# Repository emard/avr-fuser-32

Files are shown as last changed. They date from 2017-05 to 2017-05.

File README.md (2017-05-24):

# AVR-Fuser 32

3-in-1 Resurrector programmer for AVR chips

    HVPP: High-Voltage Parallel Programmer
    HVSP: High-Voltage Serial Programmer
    ISP:  In-System Programmer (SPI)

Based on [AVR-Doper](https://www.obdev.at/products/vusb/avrdoper.html)
firmware running on ATMEGA32 in DIP-40 socket.

AVRDUDE compatible, USB powered, onboard 5V->12V converter,
10-pin ISP header, 20-pin HVPP/HVSP header and 
adapter PCB for many popular DIP packages.

Quick mode without PC and avrdude: Pushbutton
erases chip to factory default state.

Complete with firmware, bootloader, kicad schematics and PCB 
for the programmer and sockets adapter.

Supported devices (I tried many but not all of them :)

    ATMEGA 8, 16, 32, 162, 168P, 328P, 16M1, 32M1, 64M1, 8515, 8535
    ATTINY 11, 13, 15, 26, 84, 85, 2313, 4313

# Remark

This is my old project, just uplodaded to github in order
not to get lost, without trying it to compile or open 
since a long time.

May need some fitting for new avr-gcc and kicad 4.x

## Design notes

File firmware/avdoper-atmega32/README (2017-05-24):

use bootloader

make fuser

press start + reset

make flash

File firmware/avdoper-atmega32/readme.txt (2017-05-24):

small capacitor GND-VCC is needed for attiny84 flash programming

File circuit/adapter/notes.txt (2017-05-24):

#!/bin/sh

# extract pdf page
pdftk HV_PROG_Adapter2.pdf cat 3 output board.pdf

# converted from pdf to ppm in 300 dpi resolution
pdftoppm -r 300 board.pdf  > board.gif

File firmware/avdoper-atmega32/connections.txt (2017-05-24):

programmer       ISP               ISP

ATMEGA8          ATMEGA162         ATTINY84
-------          ---------         --------
25 PC2     ->    SCK    8          SCK   9
26 PC3 inv <-    MISO   7          MISO  8
27 PC4     ->    MOSI   6          MOSI  7
28 PC5 inv ->    RESET  9          RESET 4
   +5V           VCC    40         VCC   1
   GND           GND    20         GND   14

ATMEGA8          ATTINY84
-------          --------
11 PD5           8
12 PD6           7
13 PD7           9
17 MOSI          2
   HVRESET       4
   GND           GND 14,13,12,10
   +5V           VCC 1

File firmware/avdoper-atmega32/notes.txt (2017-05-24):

here works HVPP and HVSP

[x] find only what the F***K enables JTAG
    on this MCU. The disabling in main is not sufficient
[x] fusereset doesn't work for hvsp,
    read signature gives 0xff, despite set or clr weak pull up SDO
[ ] sometimes there's protocolr error: (dmesg shows no usb error)
Writing |                                                    | 0% 0.00sError
sending message: error sending control message: Protocol error

[ ] consecutevely reading low/high fuse on atmega162, atmega8
    sometimes returns 0xff
    -> bringing up and down progmode causes this
    delays in leaveprogmode helped for m8
    still if there's delay after leving progmode, m8 gives errors

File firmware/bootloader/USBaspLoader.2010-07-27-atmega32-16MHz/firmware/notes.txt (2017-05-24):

useable if only read-while-write section (RWW)
0x0000-0x6fff

NRWW section 0x7000-0x77ff behaves different, 
halting cpu while writing (writing fails)
it should be possible to write there with modified code for NRWW section

it could not be possible to verify or read NRWW section

to enter bootloader,
hold "START" button, press "RESET"
release "RESET", release "START

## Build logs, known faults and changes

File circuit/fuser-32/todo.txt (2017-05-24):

[x] LED diode - padovi na donjoj strani
    nemaju solmask
[ ] za tipke rupe za pinove trebaju biti bliže
[ ] resistors 330 ohm to all 20pin lines

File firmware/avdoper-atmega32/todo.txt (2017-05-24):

HVPP mode:

[x] fuser reads 1st byte of signature, all the rest are 0xff
    target chip was not fully inserted into socket

byte eeprom access doesn't work
(writes just 0, reads wrong)

(rewrite count tracking)

avrdude -t 
write eeprom 0 1
-> instead of 1 it writes 0 to eeprom

dump eeprom 0 6
-> works correctly

write to eeprom in byte mode in ISP mode works correctly
write to eeprom in page mode in hvpp works correctly

works first time, then fails

[x] fix control message timeout in version 1.02
    disabled cdc support, enabled fast crc routine
    continuous verification now works w/o error

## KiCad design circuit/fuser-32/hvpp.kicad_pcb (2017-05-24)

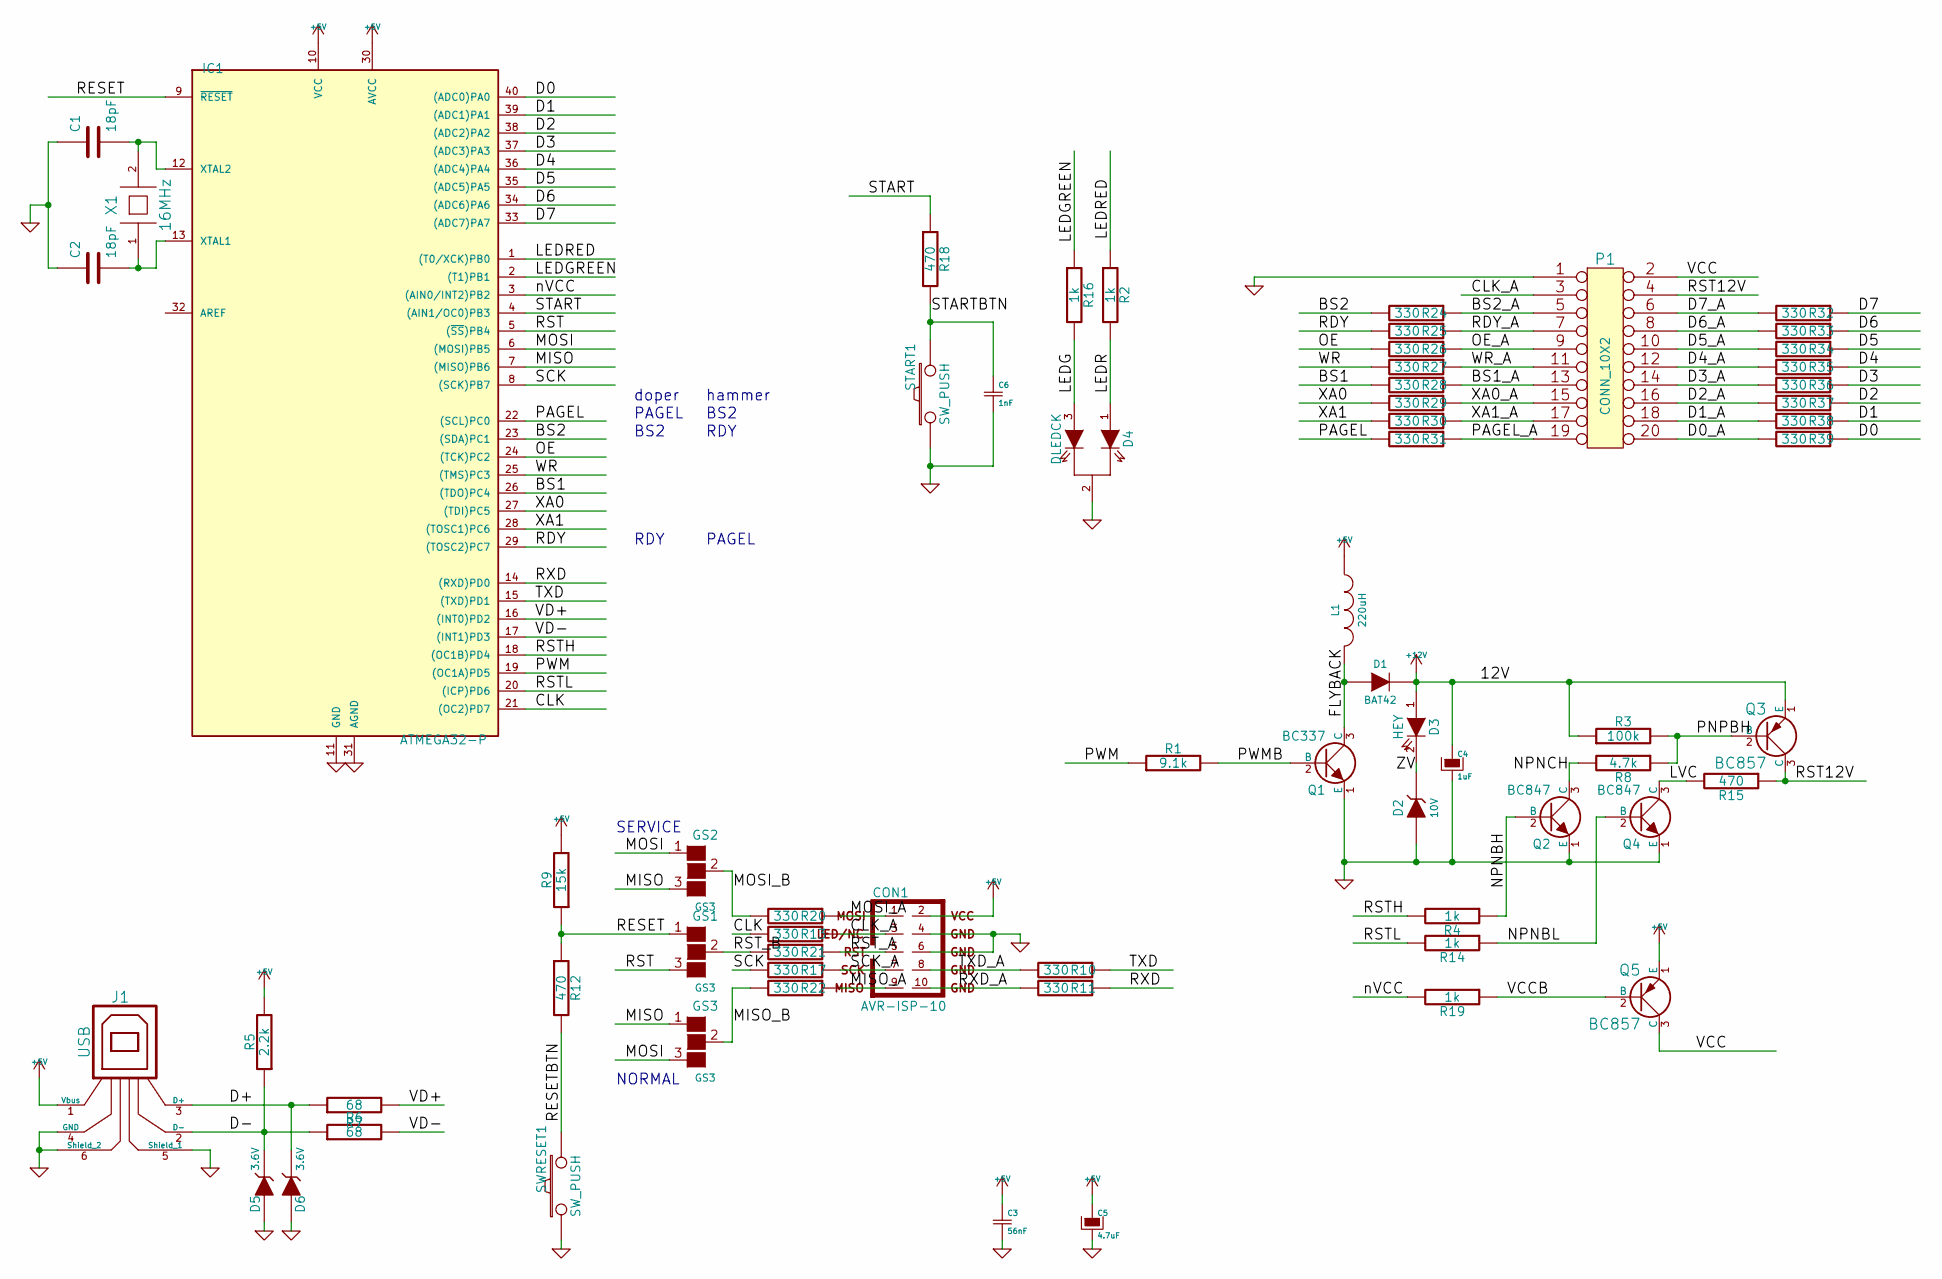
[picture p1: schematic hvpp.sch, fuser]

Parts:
C1, C2: 18pF
C3: 56nF
C4: 1uF
C5: 4.7uF
C6: 1nF
CON1: AVR-ISP-10
D1: BAT42
D2: 10V
D3: HEY
D4: DLEDCK
D5, D6: 3.6V
GS1, GS2, GS3: GS3
IC1: ATMEGA32-P; DIL40
J1: USB
L1: 220uH
P1: CONN_10X2
Q1: BC337
Q2, Q4: BC847
Q3, Q5: BC857
R1: 9.1k
R2, R4, R14, R16, R19: 1k
R3: 100k
R5: 2.2k
R6, R7: 68
R8: 4.7k
R9: 15k
R10, R11, R13, R17, R20, R21, R22, R24, R25, R26, R27, R28, R29, R30, R31, R32, R33, R34, R35, R36, R37, R38, R39: 330
R12, R15, R18: 470
START1: SW_PUSH
SWRESET1: SW_PUSH
X1: 16MHz

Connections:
+5V: C3.1, C5.1, CON1.2, IC1.10 (VCC), IC1.30 (AVCC), J1.1 (Vbus), L1.1, Q5.1 (E), R5.2, R9.2
+12V: C4.1, D1.2 (K), D3.1 (A), Q3.1 (E), R3.1
/BS1: IC1.26 ((TDO)PC4), R28.2
/BS1_A: P1.13, R28.1
/BS2: IC1.23 ((SDA)PC1), R24.2
/BS2_A: P1.5, R24.1
/CLK: IC1.21 ((OC2)PD7), R13.2
/CLK_A: CON1.3, P1.3, R13.1
/D0: IC1.40 ((ADC0)PA0), R39.1
/D0_A: P1.20, R39.2
/D1: IC1.39 ((ADC1)PA1), R38.1
/D1_A: P1.18, R38.2
/D2: IC1.38 ((ADC2)PA2), R37.1
/D2_A: P1.16, R37.2
/D3: IC1.37 ((ADC3)PA3), R36.1
/D3_A: P1.14, R36.2
/D4: IC1.36 ((ADC4)PA4), R35.1
/D4_A: P1.12, R35.2
/D5: IC1.35 ((ADC5)PA5), R34.1
/D5_A: P1.10, R34.2
/D6: IC1.34 ((ADC6)PA6), R33.1
/D6_A: P1.8, R33.2
/D7: IC1.33 ((ADC7)PA7), R32.1
/D7_A: P1.6, R32.2
/D+: D6.2 (K), J1.3 (D+), R7.1
/D-: D5.2 (K), J1.2 (D-), R5.1, R6.1
/FLYBACK: D1.1 (A), L1.2, Q1.3 (C)
/LEDG: D4.3 (AGREEN), R16.2
/LEDGREEN: IC1.2 ((T1)PB1), R16.1
/LEDR: D4.1 (ARED), R2.2
/LEDRED: IC1.1 ((T0/XCK)PB0), R2.1
/LVC: Q4.3 (C), R15.2
/MISO: GS2.3 (G3), GS3.1 (G1), IC1.7 ((MISO)PB6)
/MISO_A: CON1.9, R22.1
/MISO_B: GS3.2 (G2), R22.2
/MOSI: GS2.1 (G1), GS3.3 (G3), IC1.6 ((MOSI)PB5)
/MOSI_A: CON1.1, R20.1
/MOSI_B: GS2.2 (G2), R20.2
/NPNBH: Q2.2 (B), R4.1
/NPNBL: Q4.2 (B), R14.1
/NPNCH: Q2.3 (C), R8.2
/OE: IC1.24 ((TCK)PC2), R26.2
/OE_A: P1.9, R26.1
/PAGEL: IC1.22 ((SCL)PC0), R31.2
/PAGEL_A: P1.19, R31.1
/PNPBH: Q3.2 (B), R3.2, R8.1
/PWM: IC1.19 ((OC1A)PD5), R1.1
/PWMB: Q1.2 (B), R1.2
/RDY: IC1.29 ((TOSC2)PC7), R25.2
/RDY_A: P1.7, R25.1
/RESET: GS1.1 (G1), IC1.9 (~RESET), R9.1, R12.1
/RESETBTN: R12.2, SWRESET1.2
/RST: GS1.3 (G3), IC1.5 ((~SS~)PB4)
/RST12V: P1.4, Q3.3 (C), R15.1
/RSTH: IC1.18 ((OC1B)PD4), R4.2
/RSTL: IC1.20 ((ICP)PD6), R14.2
/RST_A: CON1.5, R21.1
/RST_B: GS1.2 (G2), R21.2
/RXD: IC1.14 ((RXD)PD0), R11.1
/RXD_A: CON1.10, R11.2
/SCK: IC1.8 ((SCK)PB7), R17.2
/SCK_A: CON1.7, R17.1
/START: IC1.4 ((AIN1/OC0)PB3), R18.1
/STARTBTN: C6.1, R18.2, START1.2
/TXD: IC1.15 ((TXD)PD1), R10.1
/TXD_A: CON1.8, R10.2
/VCC: P1.2, Q5.3 (C)
/VCCB: Q5.2 (B), R19.1
/VD+: IC1.16 ((INT0)PD2), R7.2
/VD-: IC1.17 ((INT1)PD3), R6.2
/WR: IC1.25 ((TMS)PC3), R27.2
/WR_A: P1.11, R27.1
/XA0: IC1.27 ((TDI)PC5), R29.2
/XA0_A: P1.15, R29.1
/XA1: IC1.28 ((TOSC1)PC6), R30.2
/XA1_A: P1.17, R30.1
/ZV: D2.2 (K), D3.2 (K)
/nVCC: IC1.3 ((AIN0/INT2)PB2), R19.2
GND: C1.1, C2.1, C3.2, C4.2, C5.2, C6.2, CON1.4, CON1.6, D2.1 (A), D4.2 (K), D5.1 (A), D6.1 (A), IC1.11 (GND), IC1.31 (AGND), J1.4 (GND), J1.5 (Shield_1), J1.6 (Shield_2), P1.1, Q1.1 (E), Q2.1 (E), Q4.1 (E), START1.1, SWRESET1.1
unnamed: C1.2, IC1.12 (XTAL2), X1.2
unnamed: C2.2, IC1.13 (XTAL1), X1.1

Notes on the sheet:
doper
SERVICE
NORMAL
PAGEL
RDY
BS2
hammer

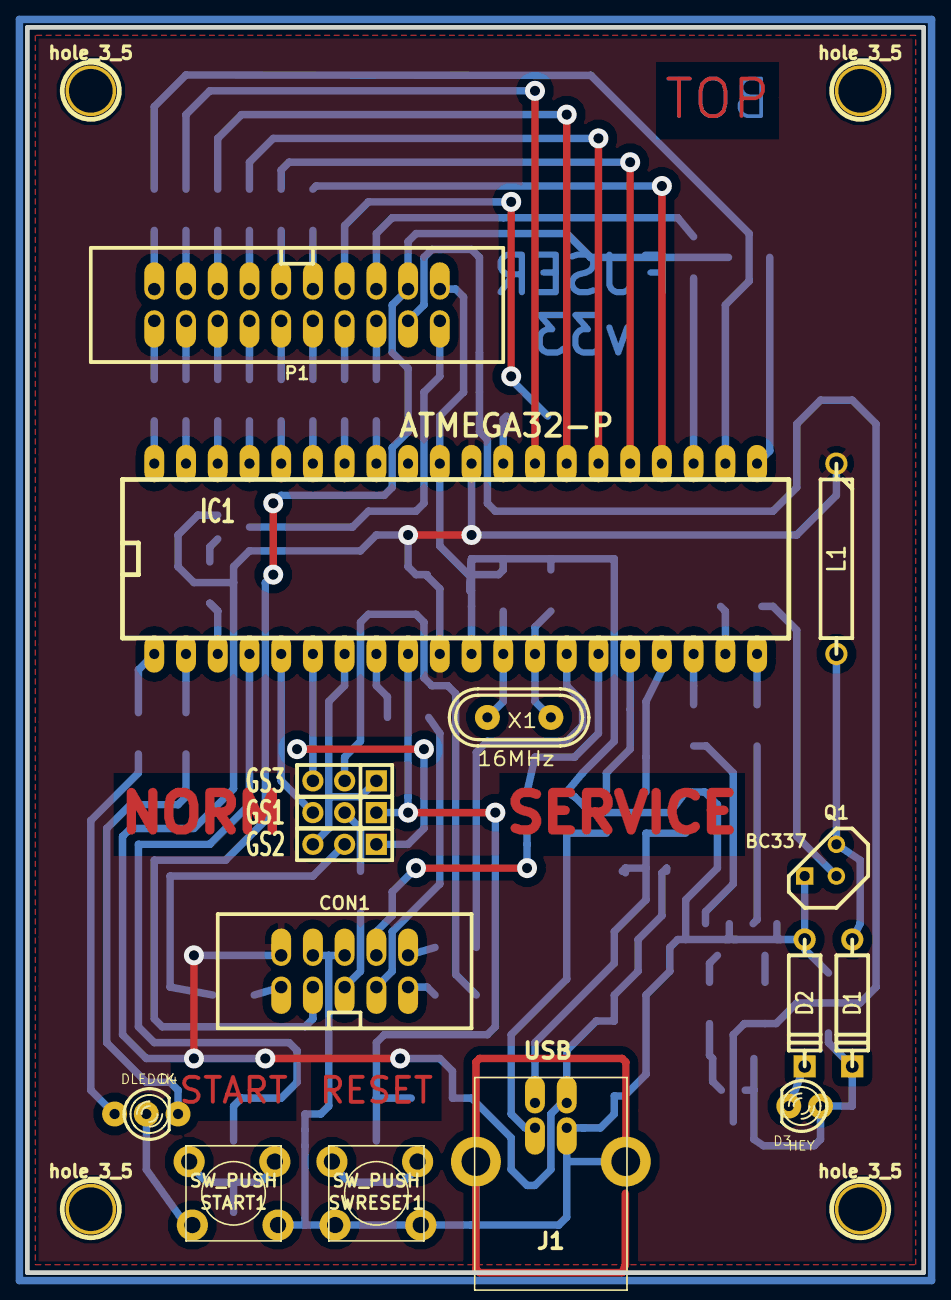
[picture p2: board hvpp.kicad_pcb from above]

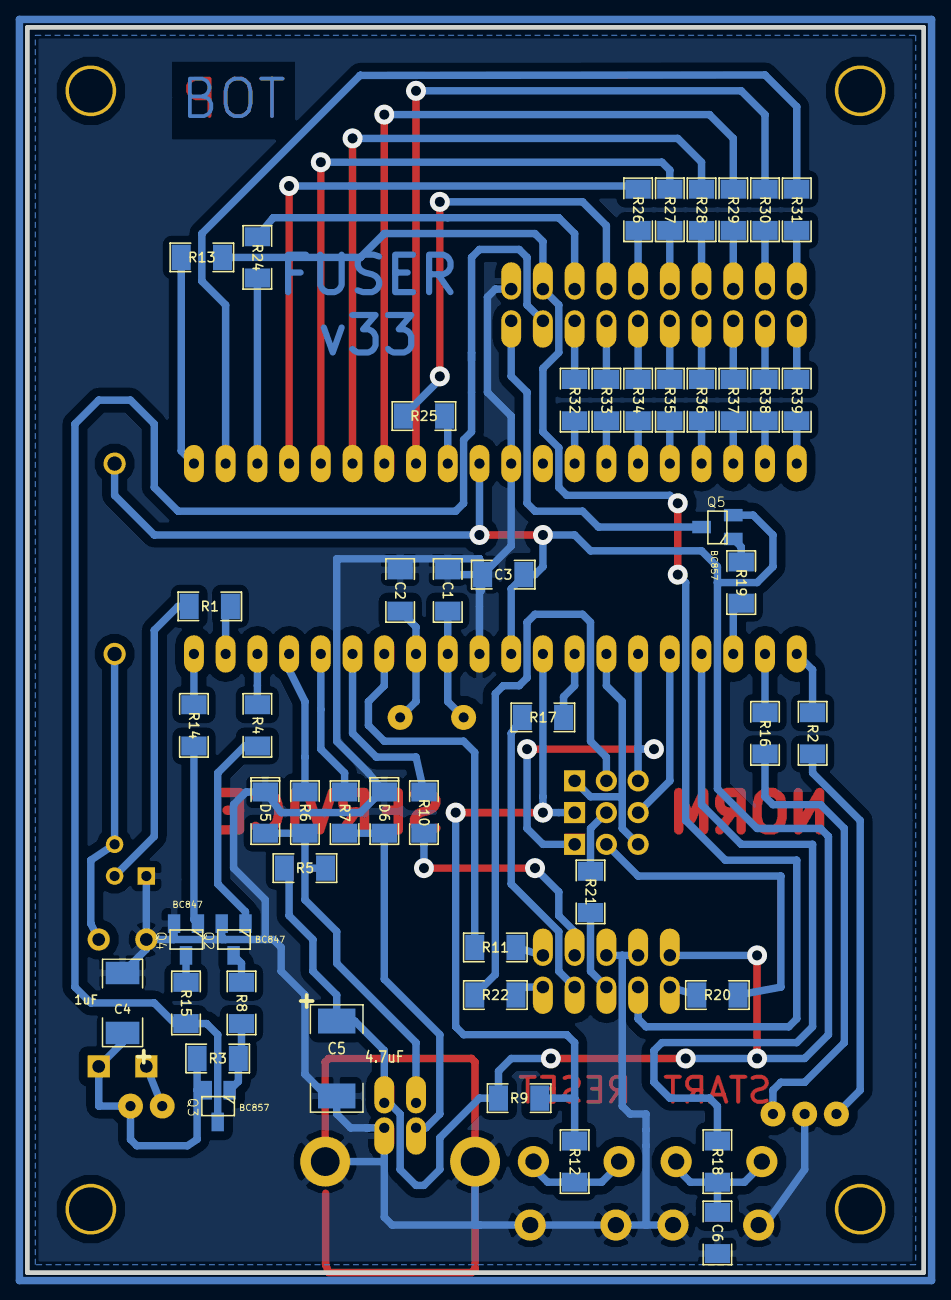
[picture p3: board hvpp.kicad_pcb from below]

Board: 2 copper layers, 71.8 x 99.7 mm, 70 parts (50 on the bottom side), 81 nets.

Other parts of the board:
hole_3_5, hole_3_5#2, hole_3_5#3, hole_3_5#4: 3.5mm; hole_3_5

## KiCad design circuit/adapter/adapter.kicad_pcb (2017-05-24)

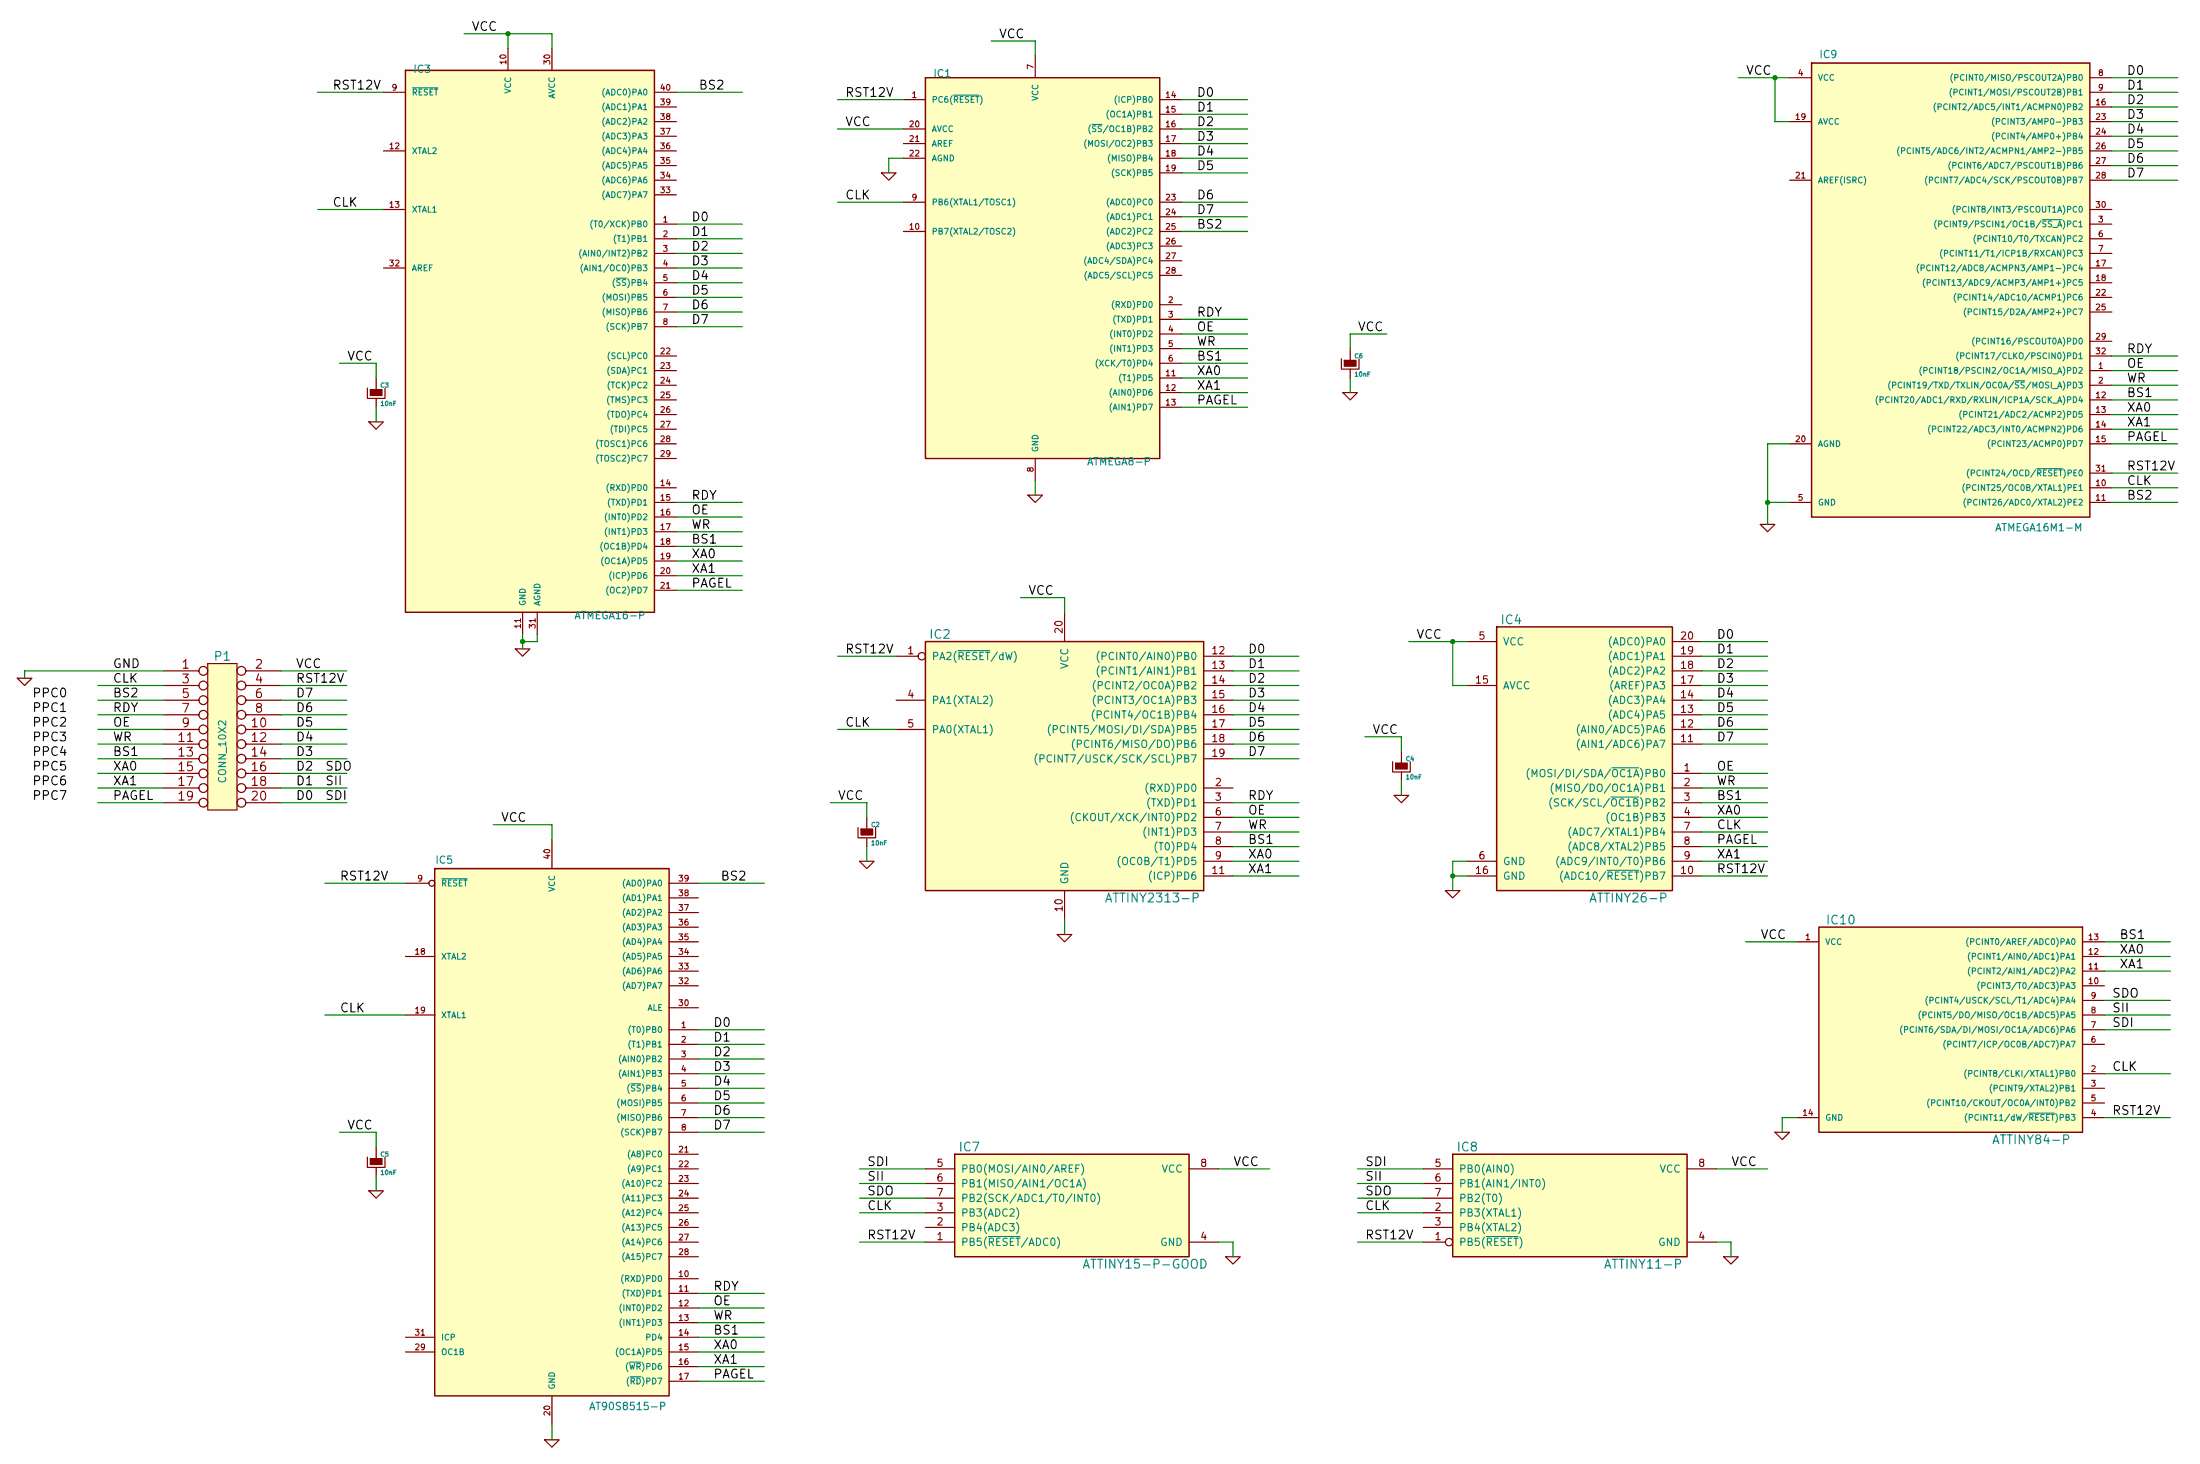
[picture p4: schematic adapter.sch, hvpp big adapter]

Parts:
C2, C3, C4, C5, C6: 10nF
IC1: ATMEGA8-P; DIL28
IC2: ATTINY2313-P; DIP20
IC3: ATMEGA16-P; DIL40
IC4: ATTINY26-P; DIP20
IC5: AT90S8515-P; DIL40
IC7: ATTINY15-P-GOOD; DIP8
IC8: ATTINY11-P; DIP8
IC9: ATMEGA16M1-M; QFN32
IC10: ATTINY84-P; DIP14
P1: CONN_10X2

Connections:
/BS1: IC1.6 ((XCK/T0)PD4), IC2.8 ((T0)PD4), IC3.18 ((OC1B)PD4), IC4.3 ((SCK/SCL/~OC1B~)PB2), IC5.14 (PD4), IC9.12 ((PCINT20/ADC1/RXD/RXLIN/ICP1A/SCK_A)PD4), IC10.13 ((PCINT0/AREF/ADC0)PA0), P1.13
/BS2: IC1.25 ((ADC2)PC2), IC3.40 ((ADC0)PA0), IC5.39 ((AD0)PA0), IC9.11 ((PCINT26/ADC0/XTAL2)PE2), P1.5
/CLK: IC1.9 (PB6(XTAL1/TOSC1)), IC2.5 (PA0(XTAL1)), IC3.13 (XTAL1), IC4.7 ((ADC7/XTAL1)PB4), IC5.19 (XTAL1), IC7.3 (PB3(ADC2)), IC8.2 (PB3(XTAL1)), IC9.10 ((PCINT25/OC0B/XTAL1)PE1), IC10.2 ((PCINT8/CLKI/XTAL1)PB0), P1.3
/D0: IC1.14 ((ICP)PB0), IC2.12 ((PCINT0/AIN0)PB0), IC3.1 ((T0/XCK)PB0), IC4.20 ((ADC0)PA0), IC5.1 ((T0)PB0), IC7.5 (PB0(MOSI/AIN0/AREF)), IC8.5 (PB0(AIN0)), IC9.8 ((PCINT0/MISO/PSCOUT2A)PB0), IC10.7 ((PCINT6/SDA/DI/MOSI/OC1A/ADC6)PA6), P1.20
/D1: IC1.15 ((OC1A)PB1), IC2.13 ((PCINT1/AIN1)PB1), IC3.2 ((T1)PB1), IC4.19 ((ADC1)PA1), IC5.2 ((T1)PB1), IC7.6 (PB1(MISO/AIN1/OC1A)), IC8.6 (PB1(AIN1/INT0)), IC9.9 ((PCINT1/MOSI/PSCOUT2B)PB1), IC10.8 ((PCINT5/DO/MISO/OC1B/ADC5)PA5), P1.18
/D2: IC1.16 ((~SS~/OC1B)PB2), IC2.14 ((PCINT2/OC0A)PB2), IC3.3 ((AIN0/INT2)PB2), IC4.18 ((ADC2)PA2), IC5.3 ((AIN0)PB2), IC7.7 (PB2(SCK/ADC1/T0/INT0)), IC8.7 (PB2(T0)), IC9.16 ((PCINT2/ADC5/INT1/ACMPN0)PB2), IC10.9 ((PCINT4/USCK/SCL/T1/ADC4)PA4), P1.16
/D3: IC1.17 ((MOSI/OC2)PB3), IC2.15 ((PCINT3/OC1A)PB3), IC3.4 ((AIN1/OC0)PB3), IC4.17 ((AREF)PA3), IC5.4 ((AIN1)PB3), IC9.23 ((PCINT3/AMP0-)PB3), P1.14
/D4: IC1.18 ((MISO)PB4), IC2.16 ((PCINT4/OC1B)PB4), IC3.5 ((~SS~)PB4), IC4.14 ((ADC3)PA4), IC5.5 ((~SS~)PB4), IC9.24 ((PCINT4/AMP0+)PB4), P1.12
/D5: IC1.19 ((SCK)PB5), IC2.17 ((PCINT5/MOSI/DI/SDA)PB5), IC3.6 ((MOSI)PB5), IC4.13 ((ADC4)PA5), IC5.6 ((MOSI)PB5), IC9.26 ((PCINT5/ADC6/INT2/ACMPN1/AMP2-)PB5), P1.10
/D6: IC1.23 ((ADC0)PC0), IC2.18 ((PCINT6/MISO/DO)PB6), IC3.7 ((MISO)PB6), IC4.12 ((AIN0/ADC5)PA6), IC5.7 ((MISO)PB6), IC9.27 ((PCINT6/ADC7/PSCOUT1B)PB6), P1.8
/D7: IC1.24 ((ADC1)PC1), IC2.19 ((PCINT7/USCK/SCK/SCL)PB7), IC3.8 ((SCK)PB7), IC4.11 ((AIN1/ADC6)PA7), IC5.8 ((SCK)PB7), IC9.28 ((PCINT7/ADC4/SCK/PSCOUT0B)PB7), P1.6
/OE: IC1.4 ((INT0)PD2), IC2.6 ((CKOUT/XCK/INT0)PD2), IC3.16 ((INT0)PD2), IC4.1 ((MOSI/DI/SDA/~OC1A~)PB0), IC5.12 ((INT0)PD2), IC9.1 ((PCINT18/PSCIN2/OC1A/MISO_A)PD2), P1.9
/PAGEL: IC1.13 ((AIN1)PD7), IC3.21 ((OC2)PD7), IC4.8 ((ADC8/XTAL2)PB5), IC5.17 ((~RD~)PD7), IC9.15 ((PCINT23/ACMP0)PD7), P1.19
/RDY: IC1.3 ((TXD)PD1), IC2.3 ((TXD)PD1), IC3.15 ((TXD)PD1), IC5.11 ((TXD)PD1), IC9.32 ((PCINT17/CLKO/PSCIN0)PD1), P1.7
/RST12V: IC1.1 (PC6(~RESET~)), IC2.1 (PA2(~RESET~/dW)), IC3.9 (~RESET), IC4.10 ((ADC10/~RESET~)PB7), IC5.9 (~RESET), IC7.1 (PB5(~RESET~/ADC0)), IC8.1 (PB5(~RESET~)), IC9.31 ((PCINT24/OCD/~RESET~)PE0), IC10.4 ((PCINT11/dW/~RESET~)PB3), P1.4
/VCC: C2.1, C3.1, C4.1, C5.1, C6.1, IC1.7 (VCC), IC1.20 (AVCC), IC2.20 (VCC), IC3.10 (VCC), IC3.30 (AVCC), IC4.5 (VCC), IC4.15 (AVCC), IC5.40 (VCC), IC7.8 (VCC), IC8.8 (VCC), IC9.4 (VCC), IC9.19 (AVCC), IC10.1 (VCC), P1.2
/WR: IC1.5 ((INT1)PD3), IC2.7 ((INT1)PD3), IC3.17 ((INT1)PD3), IC4.2 ((MISO/DO/OC1A)PB1), IC5.13 ((INT1)PD3), IC9.2 ((PCINT19/TXD/TXLIN/OC0A/~SS~/MOSI_A)PD3), P1.11
/XA0: IC1.11 ((T1)PD5), IC2.9 ((OC0B/T1)PD5), IC3.19 ((OC1A)PD5), IC4.4 ((OC1B)PB3), IC5.15 ((OC1A)PD5), IC9.13 ((PCINT21/ADC2/ACMP2)PD5), IC10.12 ((PCINT1/AIN0/ADC1)PA1), P1.15
/XA1: IC1.12 ((AIN0)PD6), IC2.11 ((ICP)PD6), IC3.20 ((ICP)PD6), IC4.9 ((ADC9/INT0/T0)PB6), IC5.16 ((~WR~)PD6), IC9.14 ((PCINT22/ADC3/INT0/ACMPN2)PD6), IC10.11 ((PCINT2/AIN1/ADC2)PA2), P1.17
GND: C2.2, C3.2, C4.2, C5.2, C6.2, IC1.8 (GND), IC1.22 (AGND), IC2.10 (GND), IC3.11 (GND), IC3.31 (AGND), IC4.6 (GND), IC4.16 (GND), IC5.20 (GND), IC7.4 (GND), IC8.4 (GND), IC9.5 (GND), IC9.20 (AGND), IC10.14 (GND), P1.1

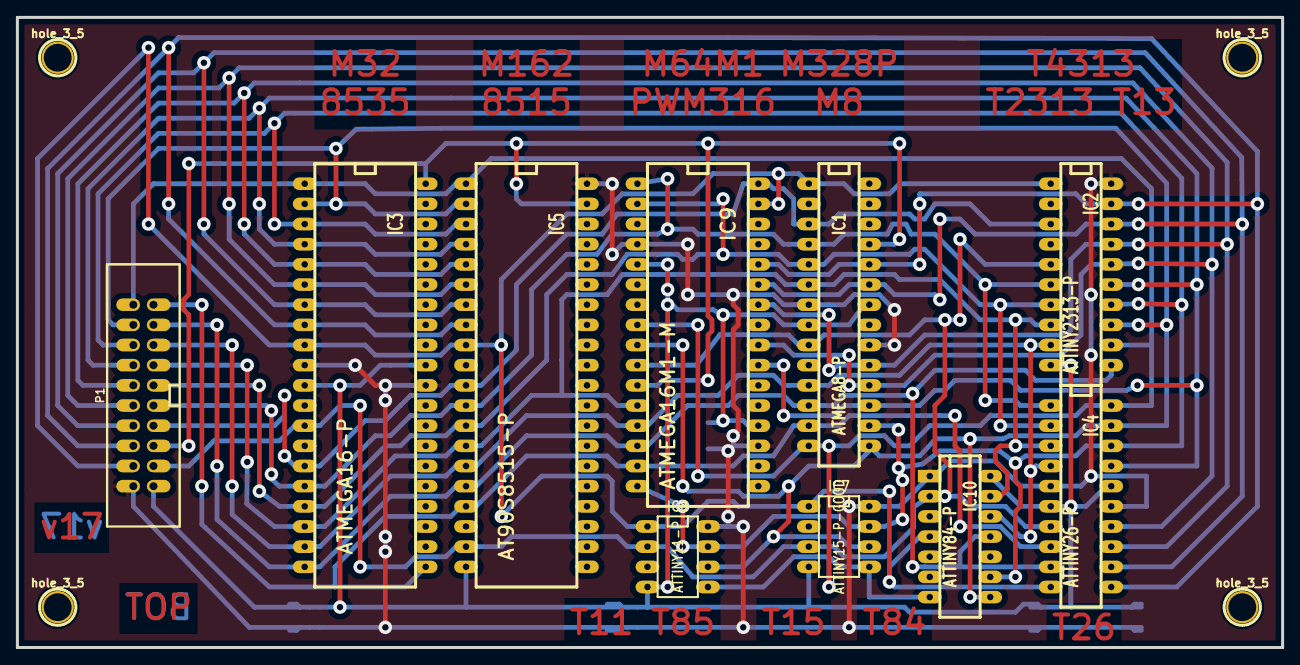
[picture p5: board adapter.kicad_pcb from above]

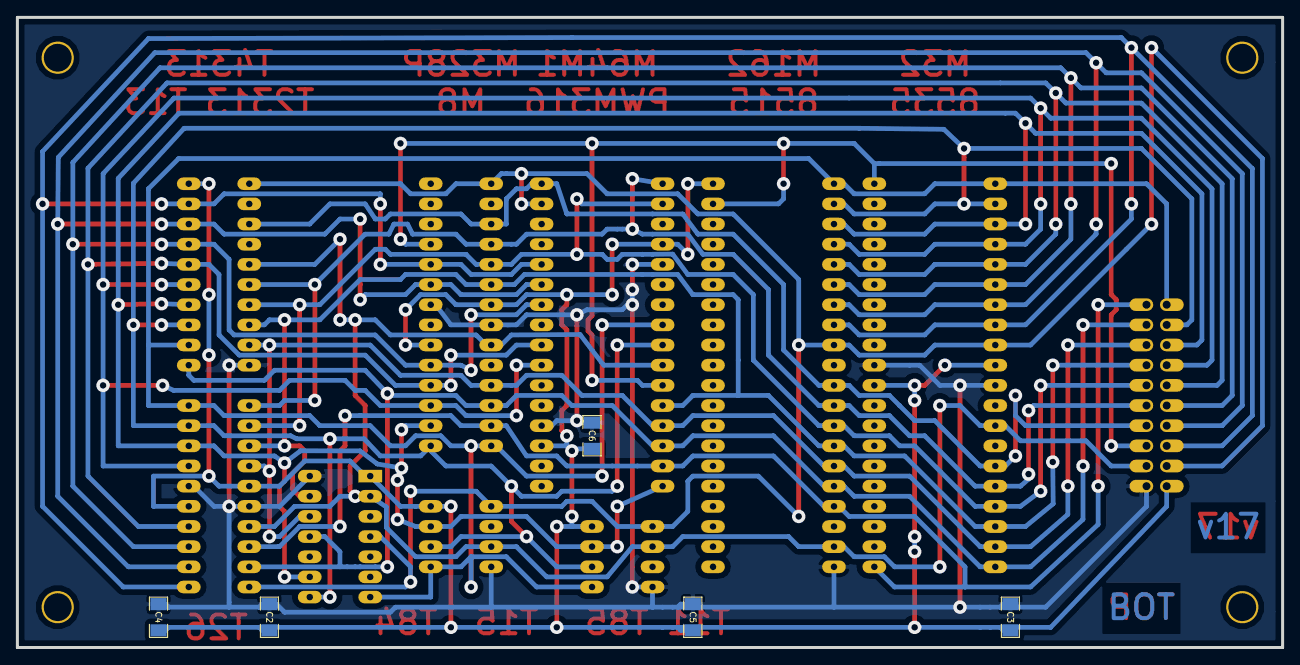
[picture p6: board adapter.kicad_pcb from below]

Board: 2 copper layers, 159.4 x 79.4 mm, 19 parts (5 on the bottom side), 20 nets.

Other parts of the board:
hole_3_5, hole_3_5#2, hole_3_5#3, hole_3_5#4: 3.5mm; hole_3_5

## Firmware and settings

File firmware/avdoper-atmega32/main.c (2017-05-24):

/* Name: main.c
 * Project: AVR-Doper
 * Author: Christian Starkjohann <cs@obdev.at>
 * Creation Date: 2006-06-21
 * Tabsize: 4
 * Copyright: (c) 2006 by Christian Starkjohann, all rights reserved.
 * License: GNU GPL v2 (see License.txt) or proprietary (CommercialLicense.txt)
 * Revision: $Id: main.c 702 2008-11-26 20:16:54Z cs $
 */

/*
General Description:
This module implements hardware initialization and the USB interface
*/

#include "hardware.h"
#include <avr/io.h>
#include <avr/interrupt.h>
#include <avr/pgmspace.h>
#include <avr/wdt.h>
#include <util/delay.h>
#include <string.h>

#include "utils.h"
#include "usbdrv.h"
#include "oddebug.h"
#include "stk500protocol.h"
#include "vreg.h"
#include "serial.h"
#include "timer.h"
#include "fusereset.h"

/* ------------------------------------------------------------------------- */

/* CDC class requests: */
enum {
    SEND_ENCAPSULATED_COMMAND = 0,
    GET_ENCAPSULATED_RESPONSE,
    SET_COMM_FEATURE,
    GET_COMM_FEATURE,
    CLEAR_COMM_FEATURE,
    SET_LINE_CODING = 0x20,
    GET_LINE_CODING,
    SET_CONTROL_LINE_STATE,
    SEND_BREAK
};

/* defines for 'requestType' */
#define REQUEST_TYPE_LINE_CODING    0   /* CDC GET/SET_LINE_CODING */
#define REQUEST_TYPE_HID_FIRST      1   /* first block of HID reporting */
#define REQUEST_TYPE_HID_SUBSEQUENT 2   /* subsequent block of HID reporting */
#define REQUEST_TYPE_HID_DEBUGDATA  3   /* read/write data from/to debug interface */
#define REQUEST_TYPE_VENDOR         4   /* vendor request for get/set debug data */

/* ------------------------------------------------------------------------- */

#if ENABLE_CDC_INTERFACE
static uchar    modeBuffer[7] = {0x80, 0x25, 0, 0, 0, 0, 8};  /* default: 9600 bps, 8n1 */
#   if USE_DCD_REPORTING
static uchar    intr3Status;
#   endif
#endif
#if ENABLE_HID_INTERFACE
static uchar    hidStatus;
#endif
static uchar    requestType;
static uchar    useHIDInterface;

#if ENABLE_CDC_INTERFACE
static const PROGMEM char deviceDescrCDC[] = {    /* USB device descriptor */
    18,         /* sizeof(usbDescriptorDevice): length of descriptor in bytes */
    USBDESCR_DEVICE,        /* descriptor type */
    0x10, 0x01,             /* USB version supported */
    0x02,                   /* device class: CDC */
    0,                      /* subclass */
    0,                      /* protocol */
    8,                      /* max packet size */
    USB_CFG_VENDOR_ID,      /* 2 bytes */
    0xe1, 0x05,             /* 2 bytes: shared PID for CDC-ACM devices */
    USB_CFG_DEVICE_VERSION, /* 2 bytes */
    1,                      /* manufacturer string index */
    2,                      /* product string index */
    3,                      /* serial number string index */
    1,                      /* number of configurations */
};

static const PROGMEM char configDescrCDC[] = {   /* USB configuration descriptor */
    9,          /* sizeof(usbDescriptorConfiguration): length of descriptor in bytes */
    USBDESCR_CONFIG,    /* descriptor type */
    67, 0,      /* total length of data returned (including inlined descriptors) */
    2,          /* number of interfaces in this configuration */
    1,          /* index of this configuration */
    0,          /* configuration name string index */
#if USB_CFG_IS_SELF_POWERED
    USBATTR_SELFPOWER,  /* attributes */
#else
    USBATTR_BUSPOWER,   /* attributes */
#endif
    USB_CFG_MAX_BUS_POWER/2,            /* max USB current in 2mA units */

    /* interface descriptors follow inline: */
    /* Interface Descriptor for CDC-ACM Control  */
    9,          /* sizeof(usbDescrInterface): length of descriptor in bytes */
    USBDESCR_INTERFACE, /* descriptor type */
    0,          /* index of this interface */
    0,          /* alternate setting for this interface */
    1,          /* endpoints excl 0: number of endpoint descriptors to follow */
    USB_CFG_INTERFACE_CLASS,    /* see usbconfig.h */
    USB_CFG_INTERFACE_SUBCLASS,
    USB_CFG_INTERFACE_PROTOCOL,
    0,          /* string index for interface */

    /* CDC Class-Specific descriptors */
    5,          /* sizeof(usbDescrCDC_HeaderFn): length of descriptor in bytes */
    0x24,       /* descriptor type */
    0,          /* Subtype: header functional descriptor */
    0x10, 0x01, /* CDC spec release number in BCD */

    4,          /* sizeof(usbDescrCDC_AcmFn): length of descriptor in bytes */
    0x24,       /* descriptor type */
    2,          /* Subtype: abstract control management functional descriptor */
    0x02,       /* capabilities: SET_LINE_CODING, GET_LINE_CODING, SET_CONTROL_LINE_STATE */

    5,          /* sizeof(usbDescrCDC_UnionFn): length of descriptor in bytes */
    0x24,       /* descriptor type */
    6,          /* Subtype: union functional descriptor */
    0,          /* CDC_COMM_INTF_ID: master interface (control) */
    1,          /* CDC_DATA_INTF_ID: slave interface (data) */

    5,          /* sizeof(usbDescrCDC_CallMgtFn): length of descriptor in bytes */
    0x24,       /* descriptor type */
    1,          /* Subtype: call management functional descriptor */
    0x03,       /* capabilities: allows management on data interface, handles call management by itself */
    1,          /* CDC_DATA_INTF_ID: interface used for call management */

    /* Endpoint Descriptor */
    7,          /* sizeof(usbDescrEndpoint) */
    USBDESCR_ENDPOINT,  /* descriptor type = endpoint */
    0x83,       /* IN endpoint number 3 */
    0x03,       /* attrib: Interrupt endpoint */
    8, 0,       /* maximum packet size */
    100,        /* in ms */

    /* Interface Descriptor for CDC-ACM Data  */
    9,          /* sizeof(usbDescrInterface): length of descriptor in bytes */
    USBDESCR_INTERFACE, /* descriptor type */
    1,          /* index of this interface */
    0,          /* alternate setting for this interface */
    2,          /* endpoints excl 0: number of endpoint descriptors to follow */
    0x0a,       /* Data Interface Class Codes */
    0,          /* interface subclass */
    0,          /* Data Interface Class Protocol Codes */
    0,          /* string index for interface */

    /* Endpoint Descriptor */
    7,          /* sizeof(usbDescrEndpoint) */
    USBDESCR_ENDPOINT,  /* descriptor type = endpoint */
    0x01,       /* OUT endpoint number 1 */
    0x02,       /* attrib: Bulk endpoint */
    HW_CDC_PACKET_SIZE, 0,  /* maximum packet size */
    0,          /* in ms */

    /* Endpoint Descriptor */
    7,          /* sizeof(usbDescrEndpoint) */
    USBDESCR_ENDPOINT,  /* descriptor type = endpoint */
    0x81,       /* IN endpoint number 1 */
    0x02,       /* attrib: Bulk endpoint */
    HW_CDC_PACKET_SIZE, 0,  /* maximum packet size */
    0,          /* in ms */
};
#endif /* ENABLE_CDC_INTERFACE */

#if ENABLE_HID_INTERFACE
static const PROGMEM char deviceDescrHID[] = {    /* USB device descriptor */
    18,         /* sizeof(usbDescriptorDevice): length of descriptor in bytes */
    USBDESCR_DEVICE,        /* descriptor type */
    0x01, 0x01,             /* USB version supported */
    0,                      /* device class: composite */
    0,                      /* subclass */
    0,                      /* protocol */
    8,                      /* max packet size */
    USB_CFG_VENDOR_ID,      /* 2 bytes */
    0xdf, 0x05,             /* 2 bytes: shared PID for HIDs */
    USB_CFG_DEVICE_VERSION, /* 2 bytes */
    1,                      /* manufacturer string index */
    2,                      /* product string index */
    0,                      /* serial number string index */
    1,                      /* number of configurations */
};

static const PROGMEM char configDescrHID[] = {    /* USB configuration descriptor */
    9,          /* sizeof(usbDescriptorConfiguration): length of descriptor in bytes */
    USBDESCR_CONFIG,/* descriptor type */
    18 + 7 + 9, 0,  /* total length of data returned (including inlined descriptors) */
    1,          /* number of interfaces in this configuration */
    1,          /* index of this configuration */
    0,          /* configuration name string index */
#if USB_CFG_IS_SELF_POWERED
    (1<<7) | USBATTR_SELFPOWER,  /* attributes */
#else
    (1<<7) | USBATTR_BUSPOWER,   /* attributes */
#endif
    USB_CFG_MAX_BUS_POWER/2,    /* max USB current in 2mA units */
/* interface descriptor follows inline: */

    9,          /* sizeof(usbDescrInterface): length of descriptor in bytes */
    USBDESCR_INTERFACE, /* descriptor type */
    0,          /* index of this interface */
    0,          /* alternate setting for this interface */
    USB_CFG_HAVE_INTRIN_ENDPOINT,   /* endpoints excl 0: number of endpoint descriptors to follow */
    3,          /* interface class: HID */
    0,          /* subclass */
    0,          /* protocol */
    0,          /* string index for interface */

    9,          /* sizeof(usbDescrHID): length of descriptor in bytes */
    USBDESCR_HID,   /* descriptor type: HID */
    0x01, 0x01, /* BCD representation of HID version */
    0x00,       /* target country code */
    0x01,       /* number of HID Report (or other HID class) Descriptor infos to follow */
    0x22,       /* descriptor type: report */
    USB_CFG_HID_REPORT_DESCRIPTOR_LENGTH, 0,  /* total length of report descriptor */

    7,          /* sizeof(usbDescrEndpoint) */
    USBDESCR_ENDPOINT,  /* descriptor type = endpoint */
    0x81,       /* IN endpoint number 1 */
    0x03,       /* attrib: Interrupt endpoint */
    8, 0,       /* maximum packet size */
    USB_CFG_INTR_POLL_INTERVAL, /* in ms */
};

const PROGMEM char usbDescriptorHidReport[60] = {
    0x06, 0x00, 0xff,              // USAGE_PAGE (Generic Desktop)
    0x09, 0x01,                    // USAGE (Vendor Usage 1)
    0xa1, 0x01,                    // COLLECTION (Application)
    0x15, 0x00,                    //   LOGICAL_MINIMUM (0)
    0x26, 0xff, 0x00,              //   LOGICAL_MAXIMUM (255)
    0x75, 0x08,                    //   REPORT_SIZE (8)

    0x85, 0x01,                    //   REPORT_ID (1)
    0x95, 0x0e,                    //   REPORT_COUNT (14)
    0x09, 0x00,                    //   USAGE (Undefined)
    0xb2, 0x02, 0x01,              //   FEATURE (Data,Var,Abs,Buf)

    0x85, 0x02,                    //   REPORT_ID (2)
    0x95, 0x1e,                    //   REPORT_COUNT (30)
    0x09, 0x00,                    //   USAGE (Undefined)
    0xb2, 0x02, 0x01,              //   FEATURE (Data,Var,Abs,Buf)

    0x85, 0x03,                    //   REPORT_ID (3)
    0x95, 0x3e,                    //   REPORT_COUNT (62)
    0x09, 0x00,                    //   USAGE (Undefined)
    0xb2, 0x02, 0x01,              //   FEATURE (Data,Var,Abs,Buf)

    0x85, 0x04,                    //   REPORT_ID (4)
    0x95, 0x7e,                    //   REPORT_COUNT (126)
    0x09, 0x00,                    //   USAGE (Undefined)
    0xb2, 0x02, 0x01,              //   FEATURE (Data,Var,Abs,Buf)

    0x85, 0x05,                    //   REPORT_ID (5) [for debug interface]
    0x95, 0x3e,                    //   REPORT_COUNT (62)
    0x09, 0x00,                    //   USAGE (Undefined)
    0xb2, 0x02, 0x01,              //   FEATURE (Data,Var,Abs,Buf)

    0xc0                           // END_COLLECTION
};
/* Note: REPORT_COUNT does not include report-ID byte */

#endif /* ENABLE_HID_INTERFACE */

/* ------------------------------------------------------------------------- */

uchar usbFunctionDescriptor(usbRequest_t *rq)
{
uchar *p = NULL, len = 0, useHID = useHIDInterface;

    if(useHID){
#if ENABLE_HID_INTERFACE
        if(rq->wValue.bytes[1] == USBDESCR_DEVICE){
            p = (uchar *)deviceDescrHID;
            len = sizeof(deviceDescrHID);
        }else if(rq->wValue.bytes[1] == USBDESCR_CONFIG){
            p = (uchar *)configDescrHID;
            len = sizeof(configDescrHID);
        }else{  /* must be HID descriptor */
            p = (uchar *)(configDescrHID + 18);
            len = 9;
        }
#endif
    }else{
#if ENABLE_CDC_INTERFACE
        if(rq->wValue.bytes[1] == USBDESCR_DEVICE){
            p = (uchar *)deviceDescrCDC;
            len = sizeof(deviceDescrCDC);
        }else{  /* must be config descriptor */
            p = (uchar *)configDescrCDC;
            len = sizeof(configDescrCDC);
        }
#endif
    }
    usbMsgPtr = p;
    return len;
}


/* ------------------------------------------------------------------------- */
/* ----------------------------- USB interface ----------------------------- */
/* ------------------------------------------------------------------------- */

uchar usbFunctionSetup(uchar data[8])
{
usbRequest_t    *rq = (void *)data;
uchar           rqType = rq->bmRequestType & USBRQ_TYPE_MASK;

    if(rqType == USBRQ_TYPE_CLASS){    /* class request type */
        if(useHIDInterface){
#if ENABLE_HID_INTERFACE
            if(rq->bRequest == USBRQ_HID_GET_REPORT || rq->bRequest == USBRQ_HID_SET_REPORT){
                hidStatus = rq->wValue.bytes[0];    /* store report ID */
                if(rq->wValue.bytes[0] == 5){   /* report ID */
                    requestType = REQUEST_TYPE_HID_DEBUGDATA;
                }else{
                    requestType = REQUEST_TYPE_HID_FIRST;
                }
                /* the driver counts the total number of bytes for us */
                return 0xff;
            }
#endif
        }else{
#if ENABLE_CDC_INTERFACE
            if(rq->bRequest == GET_LINE_CODING || rq->bRequest == SET_LINE_CODING){
                requestType = REQUEST_TYPE_LINE_CODING;
                return 0xff;
            }
#   if USE_DCD_REPORTING
            if(rq->bRequest == SET_CONTROL_LINE_STATE){
                /* Report serial state (carrier detect). On several Unix platforms,
                 * tty devices can only be opened when carrier detect is set.
                 */
                intr3Status = 2;
            }
#   endif
#endif
        }
    }
#if ENABLE_DEBUG_INTERFACE
    else if(rqType == USBRQ_TYPE_VENDOR){   /* vendor requests */
        if(rq->bRequest == 1){  /* transmit data */
            serialPutc(rq->wValue.bytes[0]);
        }else if(rq->bRequest == 2){
            requestType = REQUEST_TYPE_VENDOR;
            return 0xff;    /* handle in usbFunctionRead() */
        }
    }
#endif
    return 0;
}

uchar usbFunctionRead(uchar *data, uchar len)
{
    if(requestType == REQUEST_TYPE_LINE_CODING){
#if ENABLE_CDC_INTERFACE
        /* return the "virtual" configuration */
        memcpy(data, modeBuffer, 7);
        return 7;
#endif
    }
#if ENABLE_DEBUG_INTERFACE
    else if(requestType == REQUEST_TYPE_VENDOR){
        uchar cnt;
        for(cnt = 0; cnt < len && ringBufferHasData(&serialRingBuffer); cnt++){
            *data++ = ringBufferRead(&serialRingBuffer);
        }
        return cnt;
#if ENABLE_HID_INTERFACE
    }else if(requestType == REQUEST_TYPE_HID_DEBUGDATA){
        uchar *p = data, remaining;
        if(hidStatus == 5){ /* first call */
            *p++ = hidStatus;   /* report ID */
            *p++ = ringBufferCount(&serialRingBuffer);
            remaining = len - 2;
            hidStatus = 1;  /* continue with subsequent call */
        }else{
            remaining = len;
        }
        if(hidStatus){
            do{
                if(!ringBufferHasData(&serialRingBuffer)){
                    hidStatus = 0;
                    break;
                }
                *p++ = ringBufferRead(&serialRingBuffer);
            }while(--remaining);
        }
        return len;
#endif
    }
#endif
#if ENABLE_HID_INTERFACE
    else if(requestType == REQUEST_TYPE_HID_FIRST || requestType == REQUEST_TYPE_HID_SUBSEQUENT){
        uchar *p = data, remaining;
        if(requestType == REQUEST_TYPE_HID_FIRST){
            int cnt;
            *p++ = hidStatus;   /* report ID */
            cnt = stkGetTxCount();
            if(utilHi8(cnt)){
                *p = 255;
            }else{
                *p = cnt;     /* second byte is number of remaining bytes buffered */
            }
            p++;
            remaining = len - 2;
            requestType = REQUEST_TYPE_HID_SUBSEQUENT;
        }else{
            remaining = len;
        }
        if(hidStatus){
            do{
                int c = stkGetTxByte();
                if(c < 0){
                    hidStatus = 0;
                    break;
                }
                *p++ = c;
            }while(--remaining);
        }
        return len;
    }
#endif
    return 0;   /* error -> terminate transfer */
}

uchar usbFunctionWrite(uchar *data, uchar len)
{
    if(requestType == REQUEST_TYPE_LINE_CODING){
#if ENABLE_CDC_INTERFACE
        /* Don't know why data toggling is reset when line coding is changed, but it is... */
        USB_SET_DATATOKEN1(USBPID_DATA1);   /* enforce DATA0 token for next transfer */
        /* store the line configuration so that we can return it on request */
        memcpy(modeBuffer, data, 7);
        return 1;
#endif
    }
#if ENABLE_HID_INTERFACE
#if ENABLE_DEBUG_INTERFACE
    else if(requestType == REQUEST_TYPE_HID_DEBUGDATA){
        uchar *p = data, rval = len != 8;
        if(hidStatus == 5){ /* first call */
            hidStatus = -p[1]; /* second byte is data length */
            p += 2;
            len -= 2;
        }
        do{
            if(!hidStatus)
                break;
            serialPutc(*p++);
            hidStatus++;
        }while(--len);
        return rval;    /* the last packet must have 7 bytes insted of 8 */
    }
#endif
    else if(requestType == REQUEST_TYPE_HID_FIRST || requestType == REQUEST_TYPE_HID_SUBSEQUENT){
        uchar *p = data, rval = len != 8;
        if(requestType == REQUEST_TYPE_HID_FIRST){
            hidStatus = p[1]; /* second byte is data length */
            p += 2;
            len -= 2;
            requestType = REQUEST_TYPE_HID_SUBSEQUENT;
        }
        do{
            if(!hidStatus)
                break;
            stkSetRxChar(*p++);
            hidStatus--;
        }while(--len);
        return rval;    /* the last packet must have 7 bytes insted of 8 */
    }
#endif
    return 1;   /* error -> accept everything until end */
}

void usbFunctionWriteOut(uchar *data, uchar len)
{
#if ENABLE_CDC_INTERFACE
    do{ /* len must be at least 1 character, the driver discards zero sized packets */
        stkSetRxChar(*data++);
    }while(--len);
#endif
}

/* ------------------------------------------------------------------------- */
/* ------------------------------------------------------------------------- */
/* ------------------------------------------------------------------------- */

static void readInterfaceType(void)
{
#if ENABLE_HID_INTERFACE && ENABLE_CDC_INTERFACE
#if METABOARD_HARDWARE
    PORT_PIN_SET(HWPIN_JUMPER);                         /* set internal pull-up */
    _delay_us(1);
    useHIDInterface = !PORT_PIN_VALUE(HWPIN_JUMPER);    /* if jumper is set -> HID mode */
#else
#if 0
    PORT_DDR_SET(HWPIN_ISP_MOSI);
    PORT_PIN_SET(HWPIN_ISP_MOSI);
    PORT_DDR_CLR(HWPIN_ISP_MOSI);
    PORT_PIN_CLR(HWPIN_ISP_MOSI);   /* deactivate pullup */
#endif
    useHIDInterface = PORT_PIN_VALUE(HWPIN_JUMPER) ? 1 : 0;
#endif /* METABOARD_HARDWARE */
#elif ENABLE_HID_INTERFACE
    useHIDInterface = 1;
#elif !ENABLE_CDC_INTERFACE
#error "You must set either ENABLE_HID_INTERFACE or ENABLE_CDC_INTERFACE in hardware.h!"
#endif
}

/*
20 pin HVSP / PP connector:
    1 .... GND
    2 .... Vtarget
    3 .... HVSP SCI
    4 .... RESET
    16 ... HVSP SDO
    18 ... HVSP SII
    20 ... HVSP SDI

 * Timer usage:
 * Timer 0 [8 bit]:
 *   1/64 prescaler for timer interrupt
 * Timer 1 [16 bit]:
 *   PWM for voltage supply -> fastPWM mode
 *   f = 23.4 kHz -> prescaler = 1, 9 bit
 * Timer 2 [8 bit]:
 *   Clock generation for target device
 */

static void hardwareInit(void)
{
uchar   i;
uchar   portA = 0, portB = 0, portC = 0, portD = 0, ddrA = 0, ddrB = 0, ddrC = 0, ddrD = 0;

#if ENABLE_HVPROG
#if HW_VCC_INVERT
    UTIL_PBIT_SET(port, HWPIN_HVSP_SUPPLY);
#else
    UTIL_PBIT_CLR(port, HWPIN_HVSP_SUPPLY);
#endif
    UTIL_PBIT_SET(ddr, HWPIN_HVSP_SUPPLY);
    UTIL_PBIT_CLR(port, HWPIN_BOOST_OUT);
    UTIL_PBIT_CLR(ddr, HWPIN_BOOST_OUT);
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
int main(void)
{
    /* disable JTAG first otherwise C port lines will not work */
    MCUCSR = 1<<JTD;
    MCUCSR = 1<<JTD;

    wdt_enable(WDTO_1S);
    odDebugInit();
    DBG1(0x00, 0, 0);
#if ENABLE_DEBUG_INTERFACE
    serialInit();
#endif
    readInterfaceType();
    hardwareInit();
    vregInit();
    usbInit();
    sei();
    DBG1(0x01, 0, 0);
    for(;;){    /* main event loop */
        wdt_reset();
        pushbutton_poll();
        usbPoll();
        stkPoll();
#if ENABLE_CDC_INTERFACE
        if(!useHIDInterface && usbInterruptIsReady()){
            static uchar sendEmptyFrame = 1, buffer[HW_CDC_PACKET_SIZE];
            /* start with empty frame because the host eats the first packet -- don't know why... */
            int c;
            uchar i = 0;
            while(i < HW_CDC_PACKET_SIZE && (c = stkGetTxByte()) >= 0){
                buffer[i++] = c;
            }
            if(i > 0 || sendEmptyFrame){
                sendEmptyFrame = i;     /* send an empty block after last data block to indicate transfer end */
                usbSetInterrupt(buffer, i);
            }
        }
#endif
#if USE_DCD_REPORTING && ENABLE_CDC_INTERFACE
        /* We need to report rx and tx carrier after open attempt */
        if(intr3Status != 0 && usbInterruptIsReady3()){
            static uchar serialStateNotification[8] = {0xa1, 0x20, 0, 0, 0, 0, 2, 0};
            static uchar serialStateData[2] = {3, 0};
            if(intr3Status == 2){
                usbSetInterrupt3(serialStateNotification, 8);
            }else{
                usbSetInterrupt3(serialStateData, 2);
            }
            intr3Status--;
        }
#endif
    }
    return 0;
}

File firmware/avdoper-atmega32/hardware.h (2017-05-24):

/*
 * Name: hardware.h
 * Project: AVR-Doper
 * Author: Christian Starkjohann <cs@obdev.at>
 * Creation Date: 2006-07-05
 * Tabsize: 4
 * Copyright: (c) 2006 by Christian Starkjohann, all rights reserved.
 * License: GNU GPL v2 (see License.txt) or proprietary (CommercialLicense.txt)
 * Revision: $Id: hardware.h 566 2008-04-26 14:21:47Z cs $
 */

/*
General Description:
This module defines hardware properties and configuration choices.
*/

#ifndef __hardware_h_included__
#define __hardware_h_included__

/* configuration options: */
#define USE_DCD_REPORTING       0
/* If this option is defined to 1, the driver will report carrier detect when
 * the serial device is opened. This is useful on some Unix platforms to allow
 * using the /dev/tty* instead of /dev/cu* devices.
 * Setting this option to 0 saves a couple of bytes in flash and RAM memory.
 */
#define ENABLE_DEBUG_INTERFACE  0
/* If this option is defined to 1, the device buffers serial data (read from
 * the the ISP connector) and makes it available through vendor specific
 * requests to host based software. This is useful to display debug information
 * sent by the target.
 * Setting this option to 0 saves a couple of bytes in flash memory.
 */
#define ENABLE_HID_INTERFACE    1
/* If this option is defined to 1, the device implements a custom HID type
 * interface to send and receive STK500 serial data. If both, the CDC-ACM and
 * HID interface are enabled, a jumper selects which one is used.
 */
#define ENABLE_CDC_INTERFACE    0
/* If this option is defined to 1, the device implements a CDC-ACM modem,
 * emulating the behavior of the STK500 board on a virtual COM port.
 */
#define ENABLE_HVPROG           1
/* If this option is defined to 1, the high voltage programmer is enabled.
 */
#define HW_CDC_PACKET_SIZE      8
/* Size of bulk transfer packets. The standard demands 8 bytes, but we may
 * be better off with less. Try smaller values if the communication hangs.
 */
#define HW_DEBUG_BAUDRATE       19200
/* Bit-rate for the UART (for reading debug data from the target).
 */
#ifndef F_CPU
#error "F_CPU must be defined in compiler command line!"
/* #define F_CPU                   12000000 */
/* Our CPU frequency.
 */
#endif


/*
Port        | Function                | dir | value
------------+-------------------------+-----+-------
PORT B
  0         | HVSP Supply               [O]    1
  1 OC1A    | SMPS                      [O]    0
  2         | HVSP RESETHV / LEDHV      [O]    0
  3 OC2     | HVSP SCI / ISP target clk [O]    0
  4         | ISP driver enable         [O]    0
  5         | LED Prog active           [O]    1
  6 XTAL1   | XTAL
  7 XTAL2   | XTAL
PORT C (ADC)
  0         | SMPS feedback             [i]    0
  1         | ISP voltage sense         [i]    0
  2         | ISP SCK                   [O]    0
  3         | ISP MISO                  [I]    1
  4         | ISP MOSI                  [O]    0
  5         | ISP RESET / HVSP RESET    [O]    0
  6 RESET   | Reset
  7 n/a     | *
PORT D
  0 RxD     | ISP TxD                   [I]    1
  1 TxD     | ISP RxD                   [I]    1
  2 Int0    | USB D+                    [i]    0
  3 Int1    | USB D-                    [i]    0
  4 T0      | JUMPER Low Speed          [I]    1
  5 T1      | HVSP SII (PPD1)           [I]    1
  6 AIN0    | HVSP SDI (PPD0)           [I]    1
  7 AIN1    | HVSP SDO (PPD2)           [I]    1
*/

/* The following defines can be used with the PORT_* macros from utils.h */

#if USBASP_HARDWARE         /* USBasp hardware from www.fischl.de/usbasp/ */

#undef ENABLE_HVPROG
#define ENABLE_HVPROG       0
#define METABOARD_HARDWARE  1   /* most settings are the same as for metaboard */

#define HWPIN_LED           C, 1
#define HWPIN_ISP_SUPPLY1   C, 3    /* these pins are NC on USBasp */
#define HWPIN_ISP_SUPPLY2   C, 4

#define HWPIN_ISP_RESET     B, 2
#define HWPIN_ISP_MOSI      B, 3
#define HWPIN_ISP_MISO      B, 4
#define HWPIN_ISP_SCK       B, 5

#define HWPIN_ISP_TXD       D, 0
#define HWPIN_ISP_RXD       D, 1
#define HWPIN_USB_DPLUS     B, 1
#define HWPIN_USB_DMINUS    B, 0
#define HWPIN_JUMPER        C, 2

#elif METABOARD_HARDWARE    /* Metaboard hardware from www.obdev.at/goto?t=metaboard */

#undef ENABLE_HVPROG
#define ENABLE_HVPROG       0

#define HWPIN_LED           C, 1
#define HWPIN_ISP_SUPPLY1   C, 3
#define HWPIN_ISP_SUPPLY2   C, 4

#define HWPIN_ISP_CLK       B, 1
#define HWPIN_ISP_RESET     B, 2
#define HWPIN_ISP_MOSI      B, 3
#define HWPIN_ISP_MISO      B, 4
#define HWPIN_ISP_SCK       B, 5

#define HWPIN_ISP_TXD       D, 0
#define HWPIN_ISP_RXD       D, 1
#define HWPIN_USB_DPLUS     D, 2
#define HWPIN_USB_DMINUS    D, 4
#define HWPIN_JUMPER        D, 7

#elif HVPP_HARDWARE         /* HVPP fuse reset hardware */
/***********************************************************/

/* comment out if we don't have ISP driver */
/*
#define HWPIN_ISP_DRIVER    B, 4
*/
#define HWPIN_LED_RED       B, 0
#define HWPIN_LED_GREEN     B, 1
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

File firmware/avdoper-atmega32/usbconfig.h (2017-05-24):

/* Name: usbconfig.h
 * Project: AVR-Doper
 * Author: Christian Starkjohann
 * Creation Date: 2006-07-18
 * Tabsize: 4
 * Copyright: (c) 2006 by OBJECTIVE DEVELOPMENT Software GmbH
 * License: GNU GPL v2 (see License.txt) or proprietary (CommercialLicense.txt)
 * This Revision: $Id: usbconfig.h 566 2008-04-26 14:21:47Z cs $
 */

#ifndef __usbconfig_h_included__
#define __usbconfig_h_included__

#include "hardware.h"   /* for ENABLE_HID_INTERFACE, pins for USB */
#include "utils.h"      /* for PORT_BIT(pinspec) */
#include "version.h"

/*
General Description:
USB driver configuration for AVR-Doper.

Please note that the usbdrv contains a usbconfig-prototype.h file now. We
recommend that you use that file as a template because it will always list
the newest features and options.
*/

/* ---------------------------- Hardware Config ---------------------------- */

#define PORT_NAME(pinspec)      UTIL_ARG1(pinspec)

#define USB_CFG_IOPORTNAME      PORT_NAME(HWPIN_USB_DMINUS)
/* This is the port where the USB bus is connected. When you configure it to
 * "B", the registers PORTB, PINB and DDRB will be used.
 */
#define USB_CFG_DMINUS_BIT      PORT_BIT(HWPIN_USB_DMINUS)
/* This is the bit number in USB_CFG_IOPORT where the USB D- line is connected.
 * This may be any bit in the port.
 */
#define USB_CFG_DPLUS_BIT       PORT_BIT(HWPIN_USB_DPLUS)
/* This is the bit number in USB_CFG_IOPORT where the USB D+ line is connected.
 * This may be any bit in the port. Please note that D+ must also be connected
 * to interrupt pin INT0!
 */
#define USB_CFG_CLOCK_KHZ       (F_CPU/1000)
/* Clock rate of the AVR in MHz. Legal values are 12000, 16000 or 16500.
 * The 16.5 MHz version of the code requires no crystal, it tolerates +/- 1%
 * deviation from the nominal frequency. All other rates require a precision
 * of 2000 ppm and thus a crystal!
 * Default if not specified: 12 MHz
 */

/* ----------------------- Optional Hardware Config ------------------------ */

/* #define USB_CFG_PULLUP_IOPORTNAME   D */
/* If you connect the 1.5k pullup resistor from D- to a port pin instead of
 * V+, you can connect and disconnect the device from firmware by calling
 * the macros usbDeviceConnect() and usbDeviceDisconnect() (see usbdrv.h).
 * This constant defines the port on which the pullup resistor is connected.
 */
/* #define USB_CFG_PULLUP_BIT          4 */
/* This constant defines the bit number in USB_CFG_PULLUP_IOPORT (defined
 * above) where the 1.5k pullup resistor is connected. See description
 * above for details.
 */

/* --------------------------- Functional Range ---------------------------- */
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

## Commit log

2017-05-24 uploading my old repository
    [adapter.brd, adapter.sch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]
2017-05-24 gitignore files for kicad
2017-05-24 adapter PCB: open with Kicad 4.x and saving
    [adapter.kicad_pcb, adapter.sch]
2017-05-24 fuser-32 programmer PCB: open with kicad 4.x and saving
    [hvpp.brd, hvpp.kicad_pcb, hvpp.sch]
2017-05-24 fixing some DRC (text over copper traces) fuser32: gerbers update, preparation for seeedstudio production
    [hvpp-B.Mask.gbs, hvpp-B.SilkS.gbo, hvpp-Back.gbl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]
2017-05-24 adapter gerbers update, prepararion for seeedstudio production
    [adapter-B.Mask.gbs, adapter-B.SilkS.gbo, adapter-Back.gbl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]

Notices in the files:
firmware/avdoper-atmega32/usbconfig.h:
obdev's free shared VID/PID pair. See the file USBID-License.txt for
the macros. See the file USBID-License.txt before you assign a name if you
